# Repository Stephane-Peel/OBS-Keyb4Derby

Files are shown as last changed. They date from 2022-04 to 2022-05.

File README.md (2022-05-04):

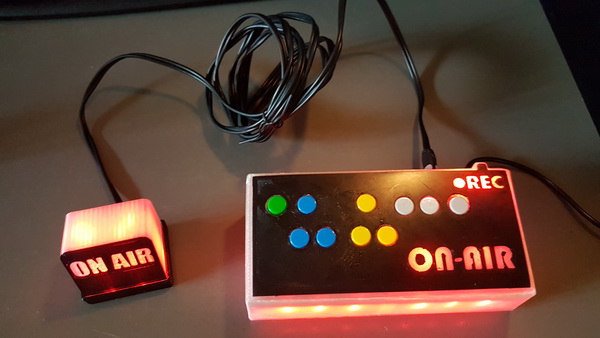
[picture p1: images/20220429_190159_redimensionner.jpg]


# OBS-Keyb4Derby

We use OBS to stream Roller Derby events.
Our setup use 3 Webcams, two C920 for the game caption and a third one to film the speakers.

We needed a simple way to manage theses sources.
I first make a quick and dirty keyboard that emulate an HID interface with an Arduino MICRO.

I later found a way to add three things to it, using the OBS Websocket (https://github.com/obsproject/obs-websocket) :
- A Record and a Stream indicator.
- A TALLY Light so the people who speak on the stream know when there are "about to be" and "On Air".

I also designed a case for the keyboard and the Tally Light.

This project is a mix of three things :
- A simple keyboard made with an arduino micro.
- Some 3D printed parts for the case and the Tally Light.
- A .NET app (very badly) forked from https://boprograms.eu/obsTally/. 
(I'am not fluent to write windows code and a total noob with .NET app Visual Studio.)

Included in this Github :
--------------------------
- A compiled "OBSTallyClientbyZoe.exe" and its source.
- The Arduino Code for Arduino
- Schematics of the keyboard 
- .STL and .OBJ to print a Case and and a Tally Light indicator.

# Build the keyboard
- An Arduino Micro : https://store.arduino.cc/products/arduino-micro
- A Verobard Stripboard. i Used some scrap laying around in my stuff so it's not really standard (size is 160mm x 73mm).
You could use this kind of board (https://www.amazon.fr/gp/product/B01KS4TC0G/ref=crt_ewc_title_oth_1?ie=UTF8&psc=1&smid=A2GZQ0HPGDFWPN) 
- Some cheap push button (https://www.amazon.fr/gp/product/B0749KNQNH/ref=ppx_yo_dt_b_search_asin_title?ie=UTF8&psc=1)
- Some few resistors, LEDs and a transistor (10K, 4.7K, 47 & 100 Ohm, a 2N3906) see attached partlist
- A 3.5mm Stereo female jack socket for the case, and a 3.5mm Stereo wire and male jack for the Tally Light.

# 3D print the case
I used a mixed material printing in 0.3mm layer height : 
First two layers are TPU, then pause the printing process and switch for clear PETG.
The back cover of the Tally Light if a full TPU print.
All the part are designed to be print with no support.

# How to use
**Please remember that OBS must be in Studio Mode for the Tally Client to work !!!**

- Install OBS Websocket if needed.
- The keyboard itself is plug and play, pressed key return F13 to F22
- Find the COM port of your Arduino.

- Start "OBSTallyClientbyZoe.exe" (the .exe need to be in a folder with all the files)
  -   Newtonsoft.Json.dll
  -   config.xml
  -   obs-websocket-dotnet.dll
  -   websocket-sharp.dll
- Setup your password and name of the scene to be advertised with the Tally light. 

> as i'd already mentionned, i'am a bad noob with .NET code it will probably advertise you with an error code, but it still work (tested on three different computers).

*note : the config.xml can also be manually edited with a text editor*
- Select the COM port of your Arduino in the software and Voila !

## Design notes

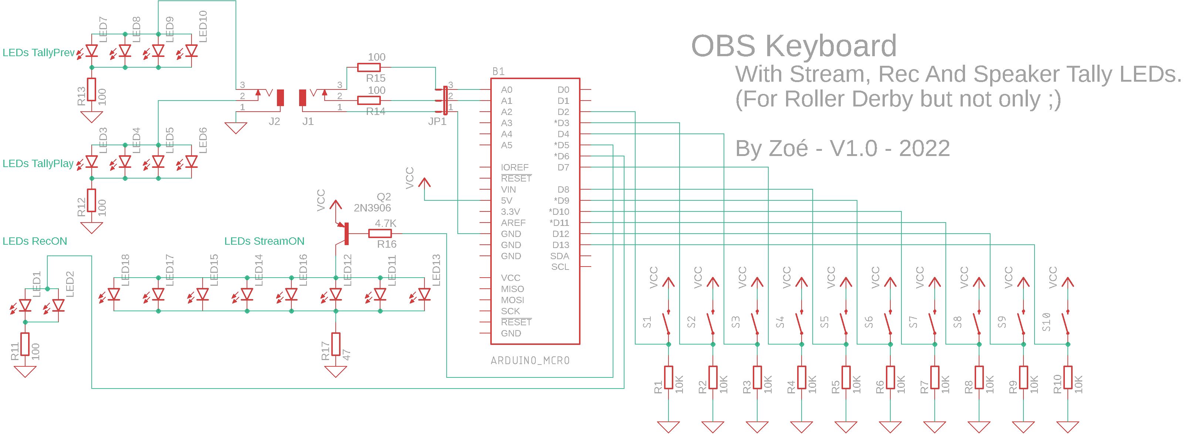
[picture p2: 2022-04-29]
Schematics/OBS-Keyb-Schematic-V1.0.png

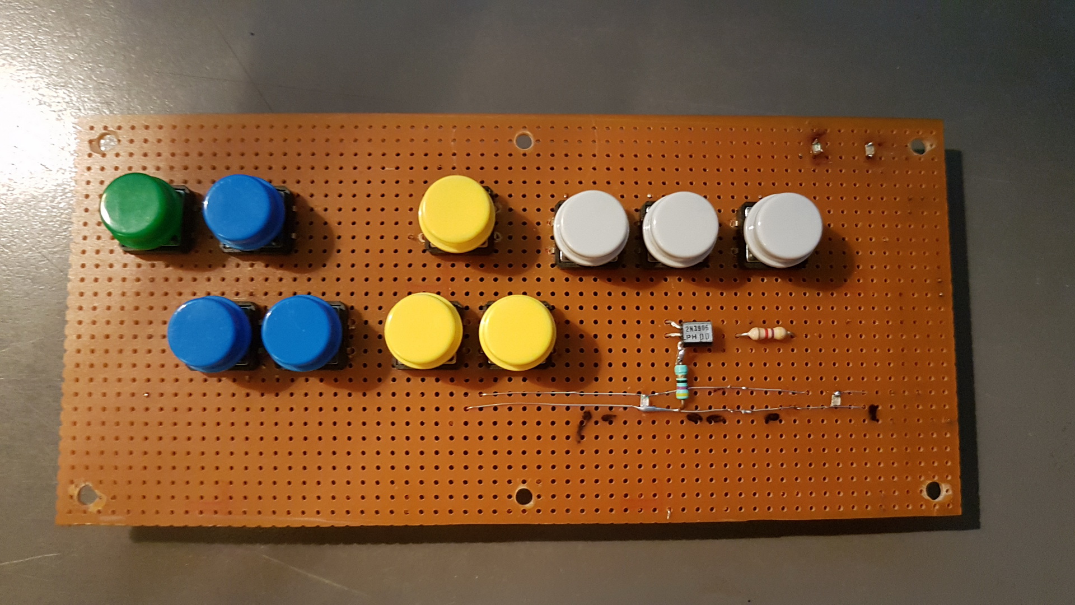
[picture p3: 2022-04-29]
Pictures To publish/20220429_205156_redimensionner.jpg

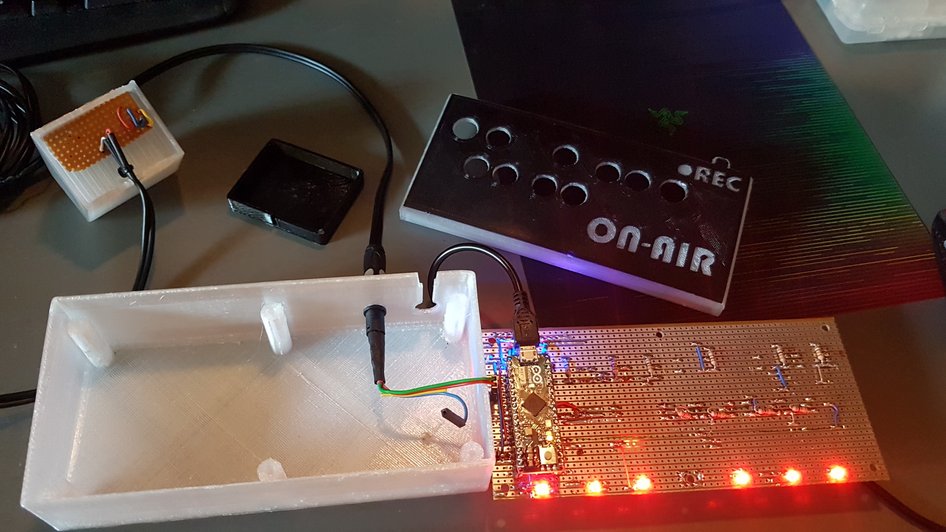
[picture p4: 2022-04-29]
Pictures To publish/20220429_190641_redimensionner.jpg

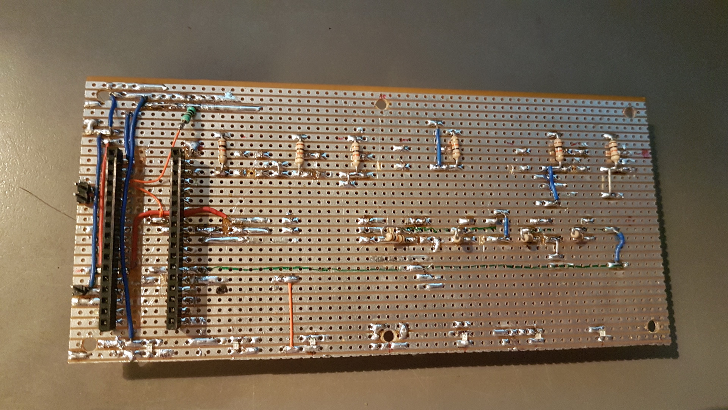
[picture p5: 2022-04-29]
Pictures To publish/20220429_205254_redimensionner.jpg

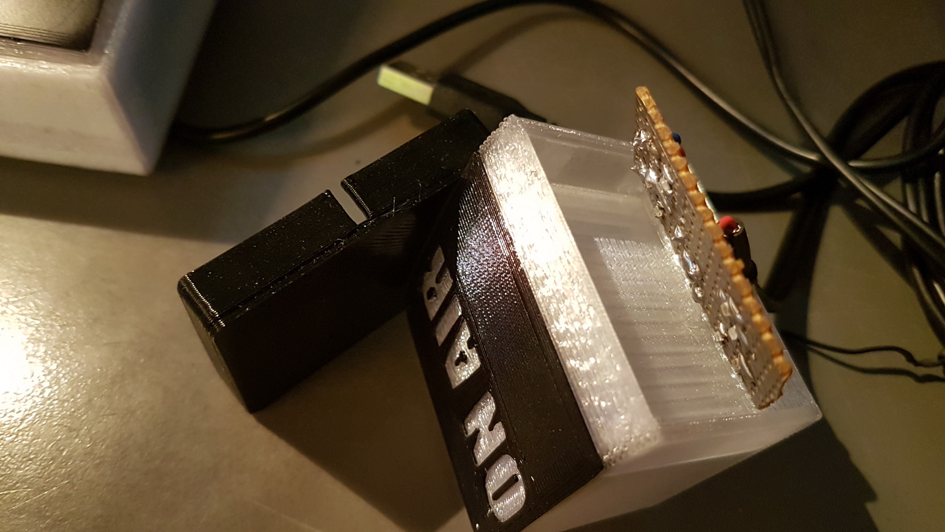
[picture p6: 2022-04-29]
Pictures To publish/20220429_210549_redimensionner.jpg

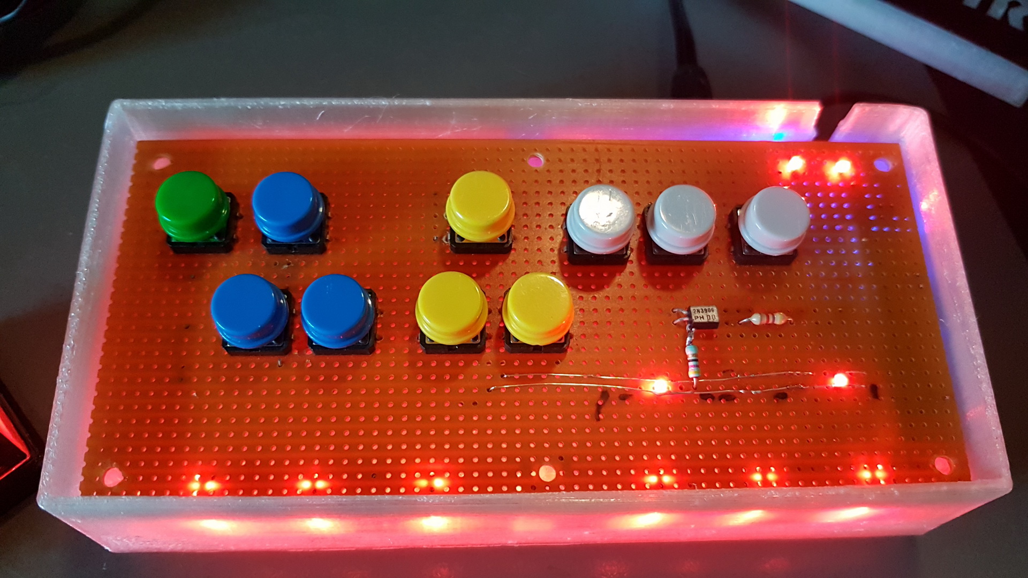
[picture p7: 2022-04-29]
Pictures To publish/20220429_190532_redimensionner.jpg

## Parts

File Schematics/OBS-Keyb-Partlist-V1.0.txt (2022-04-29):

Part     Value          Device                          Package                  

B1       ARDUINO_MCRO   ARDUINO_MCRO                    ARDUINO_MCRO             
J1                      DCJ0303                         DCJ0303                  
J2                      DCJ0303                         DCJ0303                  
JP1                     JP2E                            JP2                      
LED1                    LEDCHIPLED_0805                 CHIPLED_0805             
LED2                    LEDCHIPLED_0805                 CHIPLED_0805             
LED3                    LEDCHIPLED_0805                 CHIPLED_0805             
LED4                    LEDCHIPLED_0805                 CHIPLED_0805             
LED5                    LEDCHIPLED_0805                 CHIPLED_0805             
LED6                    LEDCHIPLED_0805                 CHIPLED_0805             
LED7                    LEDCHIPLED_0805                 CHIPLED_0805             
LED8                    LEDCHIPLED_0805                 CHIPLED_0805             
LED9                    LEDCHIPLED_0805                 CHIPLED_0805             
LED10                   LEDCHIPLED_0805                 CHIPLED_0805             
LED11                   LEDCHIPLED_0805                 CHIPLED_0805             
LED12                   LEDCHIPLED_0805                 CHIPLED_0805             
LED13                   LEDCHIPLED_0805                 CHIPLED_0805             
LED14                   LEDCHIPLED_0805                 CHIPLED_0805             
LED15                   LEDCHIPLED_0805                 CHIPLED_0805             
LED16                   LEDCHIPLED_0805                 CHIPLED_0805             
LED17                   LEDCHIPLED_0805                 CHIPLED_0805             
LED18                   LEDCHIPLED_0805                 CHIPLED_0805             
Q2       2N3906         2N3906                          TO92                     
R1       10K            R-EU_0204/5                     0204/5                   
R2       10K            R-EU_0204/5                     0204/5                   
R3       10K            R-EU_0204/5                     0204/5                   
R4       10K            R-EU_0204/5                     0204/5                   
R5       10K            R-EU_0204/5                     0204/5                   
R6       10K            R-EU_0204/5                     0204/5                   
R7       10K            R-EU_0204/5                     0204/5                   
R8       10K            R-EU_0204/5                     0204/5                   
R9       10K            R-EU_0204/5                     0204/5                   
R10      10K            R-EU_0204/5                     0204/5                   
R11      100            R-EU_0204/5                     0204/5                   
R12      100            R-EU_0204/5                     0204/5                   
R13      100            R-EU_0204/5                     0204/5                   
R14      100            R-EU_0204/5                     0204/5                   
R15      100            R-EU_0204/5                     0204/5                   
R16      4.7K           R-EU_0204/5                     0204/5                   
R17      47             R-EU_0204/5                     0204/5                   
S1                      MOMENTARY-SWITCH-SPST-PTH-6.0MM TACTILE_SWITCH_PTH_6.0MM 
S2                      MOMENTARY-SWITCH-SPST-PTH-6.0MM TACTILE_SWITCH_PTH_6.0MM 
S3                      MOMENTARY-SWITCH-SPST-PTH-6.0MM TACTILE_SWITCH_PTH_6.0MM 
S4                      MOMENTARY-SWITCH-SPST-PTH-6.0MM TACTILE_SWITCH_PTH_6.0MM 
S5                      MOMENTARY-SWITCH-SPST-PTH-6.0MM TACTILE_SWITCH_PTH_6.0MM 
S6                      MOMENTARY-SWITCH-SPST-PTH-6.0MM TACTILE_SWITCH_PTH_6.0MM 
S7                      MOMENTARY-SWITCH-SPST-PTH-6.0MM TACTILE_SWITCH_PTH_6.0MM 
S8                      MOMENTARY-SWITCH-SPST-PTH-6.0MM TACTILE_SWITCH_PTH_6.0MM 
S9                      MOMENTARY-SWITCH-SPST-PTH-6.0MM TACTILE_SWITCH_PTH_6.0MM 
S10                     MOMENTARY-SWITCH-SPST-PTH-6.0MM TACTILE_SWITCH_PTH_6.0MM

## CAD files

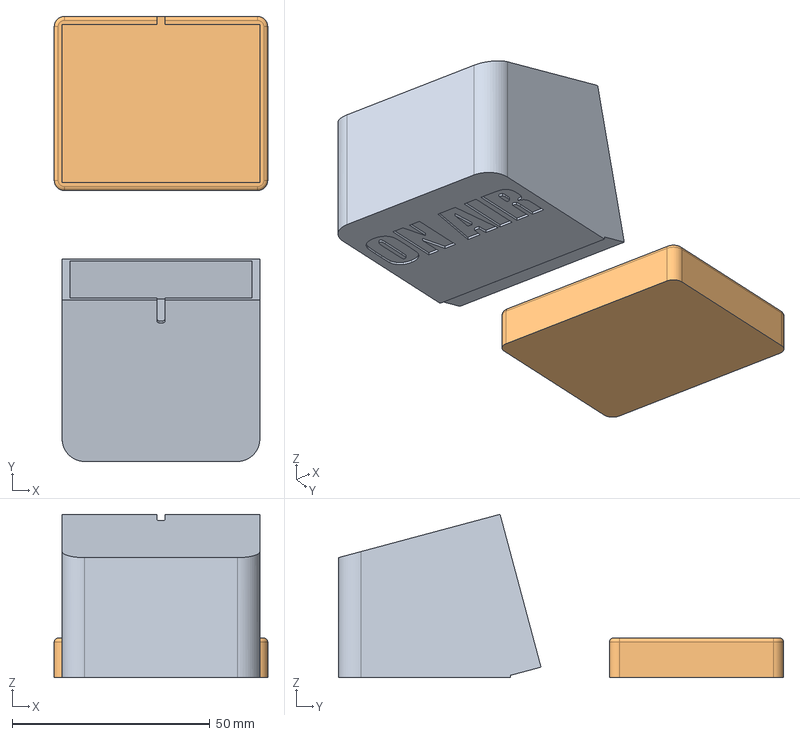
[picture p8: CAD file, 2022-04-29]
3DPrintCase/Tally Light v2.step
54.0 x 112.5 x 41.3 mm

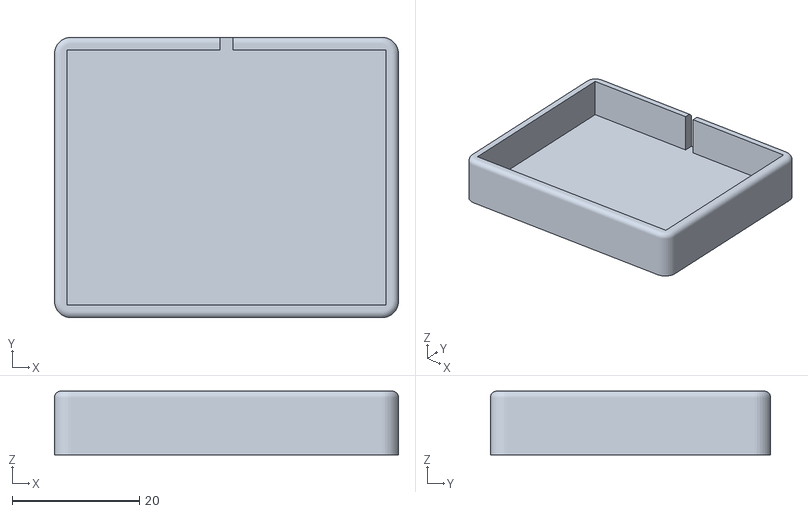
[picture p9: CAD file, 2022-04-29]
3DPrintCase/TallySpeakBAse.stl
54.0 x 44.0 x 10.0

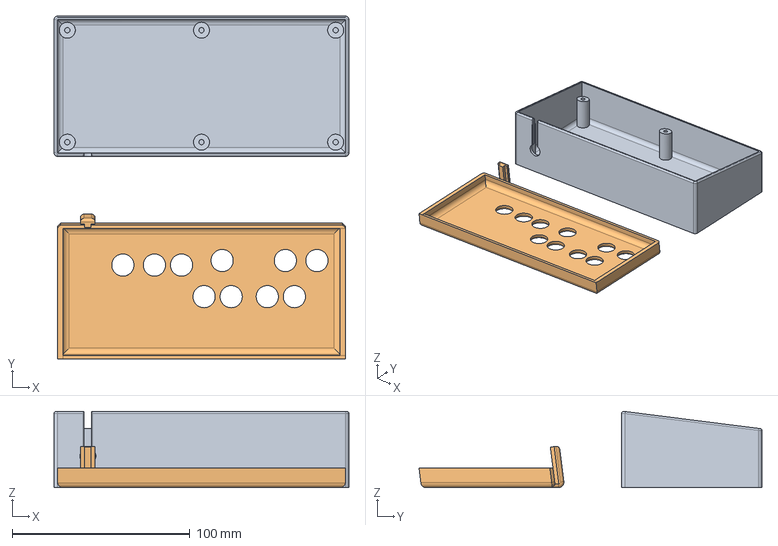
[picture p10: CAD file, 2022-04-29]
3DPrintCase/keyboardBox1 v6.step
166.0 x 193.0 x 43.0 mm

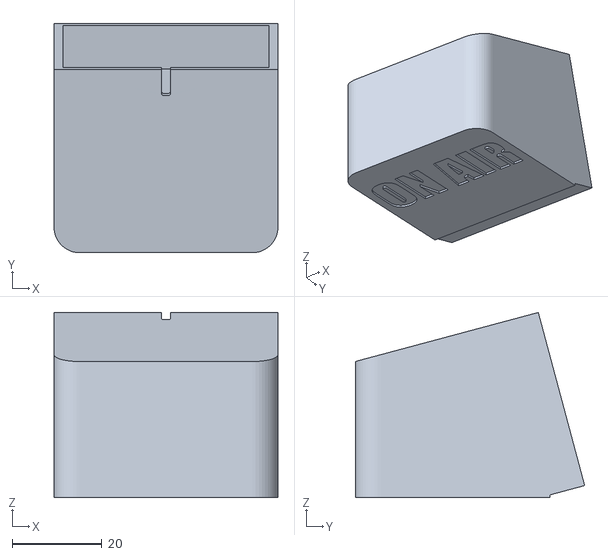
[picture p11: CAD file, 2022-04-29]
3DPrintCase/TallySpeakCorps.stl
50.0 x 51.2 x 41.3

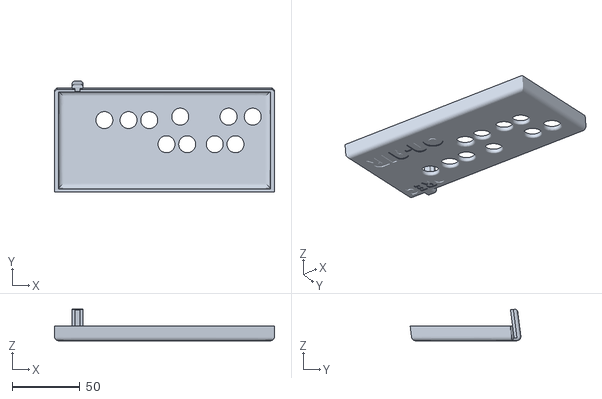
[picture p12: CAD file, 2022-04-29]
3DPrintCase/Keyboardcase1-top2+Text.stl
162.0 x 81.5 x 23.2

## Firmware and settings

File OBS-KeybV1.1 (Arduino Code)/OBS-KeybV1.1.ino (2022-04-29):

#include <Keyboard.h>

/*
  Keyboard Message test

  For the Arduino Leonardo and Micro.

  Sends a text string when a button is pressed.

  The circuit:
  - pushbutton attached from pin 4 to +5V
  - 10 kilohm resistor attached from pin 4 to ground

  created 24 Oct 2011
  modified 27 Mar 2012
  by Tom Igoe
  modified 11 Nov 2013
  by Scott Fitzgerald

  This example code is in the public domain.

  http://www.arduino.cc/en/Tutorial/KeyboardMessage
*/





const int ledStream =  5;// LED StreeamON pin
const int ledRec =  6;// LED RecON pin
const int ledTallyPrev = A0 ;
const int ledTallyPlay = A1;
bool StreamState = 0;  
bool RecState = 0;  
unsigned long previousMillisledStream = 0; 
unsigned long previousMillisLedRec = 0; 
const long interval = 1000; 
const int PwmIntervalsStream = 555; // The number of StepCounters between the output being on and off
const int PwmIntervalsRec = 555; // The number of StepCounters between the output being on and off
float RRec; // The R value in the graph equation
float RStream; // The R value in the graph equation
int ToggleSenseRec = 0;// Toggle the sense of lighting (increase/decrease)
int ToggleSenseStream = 0;// Toggle the sense of lighting (increase/decrease)
int SpeedValueStream = 8; // SpeedValue
int SpeedValueRec = 6; // SpeedValue
int StepCounterStream = 0; // StepCounter StepCounter
int StepCounterRec = 0; // StepCounter StepCounter
int HighOffsetStream = 120; // Max light Value
int LowOffsetStream = 0; // Min light Value
int HighOffsetRec = 254; // Max light Value
int LowOffsetRec = 20; // Min light Value
bool OldTally = 0;



const int buttonPin2 = 2;          // input pin for pushbutton
const int buttonPin3 = 3;          // input pin for pushbutton
const int buttonPin4 = 4;          // input pin for pushbutton
const int buttonPin7 = 7;          // input pin for pushbutton
const int buttonPin8 = 8;          // input pin for pushbutton
const int buttonPin9 = 9;          // input pin for pushbutton
const int buttonPin10 = 10;          // input pin for pushbutton
const int buttonPin11 = 11;          // input pin for pushbutton
const int buttonPin12 = 12;          // input pin for pushbutton
const int buttonPin13 = 13;          // input pin for pushbutton

int previousButtonState2 = HIGH;   // for checking the state of a pushButton
int previousButtonState3 = HIGH;   // for checking the state of a pushButton
int previousButtonState4 = HIGH;   // for checking the state of a pushButton
int previousButtonState7 = HIGH;   // for checking the state of a pushButton
int previousButtonState8 = HIGH;   // for checking the state of a pushButton
int previousButtonState9 = HIGH;   // for checking the state of a pushButton
int previousButtonState10 = HIGH;   // for checking the state of a pushButton
int previousButtonState11 = HIGH;   // for checking the state of a pushButton
int previousButtonState12 = HIGH;   // for checking the state of a pushButton
int previousButtonState13 = HIGH;   // for checking the state of a pushButton

void setup() {
  TCCR1B = TCCR1B & 0b11111000 | 0x02;
  Serial.begin(9600);
  RStream = (PwmIntervalsStream * log10(2))/(log10(255));  // Calculate the R variable (only needs to be done once at setup)
  RRec = (PwmIntervalsRec * log10(2))/(log10(255));  // Calculate the R variable (only needs to be done once at setup)

  pinMode(ledTallyPrev, OUTPUT);
  pinMode(ledTallyPlay, OUTPUT);
  pinMode(ledRec, OUTPUT); 
  pinMode(ledStream, OUTPUT);

// StartUP Blinking Pattern
analogWrite(ledRec, 255);
analogWrite(ledStream, 0);
digitalWrite(ledTallyPrev, LOW);
digitalWrite(ledTallyPlay, HIGH);
delay (500);
analogWrite(ledRec, 128);
analogWrite(ledStream, 32);
digitalWrite(ledTallyPrev, HIGH);
digitalWrite(ledTallyPlay, LOW);
delay (500);
analogWrite(ledRec, 64);
analogWrite(ledStream, 64);
digitalWrite(ledTallyPrev, LOW);
digitalWrite(ledTallyPlay, HIGH);
delay (500);
analogWrite(ledRec, 32);
analogWrite(ledStream, 128);
digitalWrite(ledTallyPrev, HIGH);
digitalWrite(ledTallyPlay, LOW);
delay (500);
analogWrite(ledRec, 0);
analogWrite(ledStream, 255);
digitalWrite(ledTallyPrev, LOW);
digitalWrite(ledTallyPlay, LOW);
delay (100);
analogWrite(ledRec, 255);
analogWrite(ledStream, 0);
digitalWrite(ledTallyPrev, HIGH);
digitalWrite(ledTallyPlay, HIGH);
delay (100);
analogWrite(ledRec, 0);
analogWrite(ledStream, 255);
digitalWrite(ledTallyPrev, LOW);
digitalWrite(ledTallyPlay, HIGH);
delay (100);
analogWrite(ledRec, 255);
analogWrite(ledStream, 0);
digitalWrite(ledTallyPrev, HIGH);
digitalWrite(ledTallyPlay, LOW);
delay (100);
analogWrite(ledRec, 0);
analogWrite(ledStream, 255);
digitalWrite(ledTallyPrev, LOW);
digitalWrite(ledTallyPlay, LOW);
    
  // make the pushButton pin an input:

 
  pinMode(buttonPin2, INPUT_PULLUP);
  pinMode(buttonPin3, INPUT_PULLUP);
  pinMode(buttonPin4, INPUT_PULLUP);
  pinMode(buttonPin7, INPUT_PULLUP);
  pinMode(buttonPin8, INPUT_PULLUP);
  pinMode(buttonPin9, INPUT_PULLUP);
  pinMode(buttonPin10, INPUT_PULLUP);
  pinMode(buttonPin11, INPUT_PULLUP);
  pinMode(buttonPin12, INPUT_PULLUP);
  pinMode(buttonPin13, INPUT_PULLUP);
  // initialize control over the keyboard:
  Keyboard.begin();
      digitalWrite(ledRec, 0);

}

void loop() {
OBSKeyboard();
LedBeatRec(); 
LedBeatStream();
Tally();

}

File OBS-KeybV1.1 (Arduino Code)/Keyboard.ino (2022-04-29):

void OBSKeyboard(){
      int buttonState2 = digitalRead(buttonPin2);
  if ((buttonState2 != previousButtonState2)
      && (buttonState2 == HIGH)) {
    Keyboard.press(KEY_F13);
    delay(300); 
    Keyboard.releaseAll();
  }
  previousButtonState2 = buttonState2;


    int buttonState3 = digitalRead(buttonPin3);
  if ((buttonState3 != previousButtonState3)
      && (buttonState3 == HIGH)) {
    Keyboard.press(KEY_F14);
     delay(300); 
     Keyboard.releaseAll();
 }
  previousButtonState3 = buttonState3;

      int buttonState4 = digitalRead(buttonPin4);
  if ((buttonState4 != previousButtonState4)
      && (buttonState4 == HIGH)) {
    Keyboard.press(KEY_F15);
      delay(300); 
      Keyboard.releaseAll();
}
  previousButtonState4 = buttonState4;

    int buttonState7 = digitalRead(buttonPin7);
  if ((buttonState7 != previousButtonState7)
      && (buttonState7 == HIGH)) {
    Keyboard.press(KEY_F16);
      delay(300); 
      Keyboard.releaseAll();
}
  previousButtonState7 = buttonState7;

      int buttonState8 = digitalRead(buttonPin8);
  if ((buttonState8 != previousButtonState8)
      && (buttonState8 == HIGH)) {
    Keyboard.press(KEY_F17);
      delay(300); 
      Keyboard.releaseAll();
}
  previousButtonState8 = buttonState8;

      int buttonState9 = digitalRead(buttonPin9);
  if ((buttonState9 != previousButtonState9)
      && (buttonState9 == HIGH)) {
    Keyboard.press(KEY_F18);
      delay(300); 
      Keyboard.releaseAll();
}
  previousButtonState9 = buttonState9;

      int buttonState10 = digitalRead(buttonPin10);
  if ((buttonState10 != previousButtonState10)
      && (buttonState10 == HIGH)) {
    Keyboard.press(KEY_F19);
      delay(300); 
      Keyboard.releaseAll();
}
  previousButtonState10 = buttonState10;

      int buttonState11 = digitalRead(buttonPin11);
  if ((buttonState11 != previousButtonState11)
      && (buttonState11 == HIGH)) {
    Keyboard.press(KEY_F20);
      delay(300); 
      Keyboard.releaseAll();
}
  previousButtonState11 = buttonState11;

   int buttonState12 = digitalRead(buttonPin12);
  if ((buttonState12 != previousButtonState12)
      && (buttonState12 == HIGH)) {
    Keyboard.press(KEY_F21);
      delay(300); 
      Keyboard.releaseAll();
}
  previousButtonState12 = buttonState12;

      int buttonState13 = digitalRead(buttonPin13);
  if ((buttonState13 != previousButtonState13)
      && (buttonState13 == HIGH)) {
    Keyboard.press(KEY_F22);
      delay(300); 
      Keyboard.releaseAll();
}
  previousButtonState13 = buttonState13;


}
